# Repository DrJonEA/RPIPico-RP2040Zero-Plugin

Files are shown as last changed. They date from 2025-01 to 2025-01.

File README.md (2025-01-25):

# RPIPico-RP2040Zero-Plugin
Use a RPI Pico in a RP2040Zero Socket for development purposes.

I love the small footprint of the RP2040Zero for some projects. Working with it in development though is a pain as the SWD ports are not exposed. To get around this I build an adapter board so I could use a Raspberry Pi Pico as a plugin for the RP2040 Zero during development.

Included in this repo is the kikad  files and an example project.

The adapter also has a reset switch on it and three LED. One is permanently on. The other two are connected to GP20 and GP21 via jumpers. So you can choose to conect these or not into the circuit.

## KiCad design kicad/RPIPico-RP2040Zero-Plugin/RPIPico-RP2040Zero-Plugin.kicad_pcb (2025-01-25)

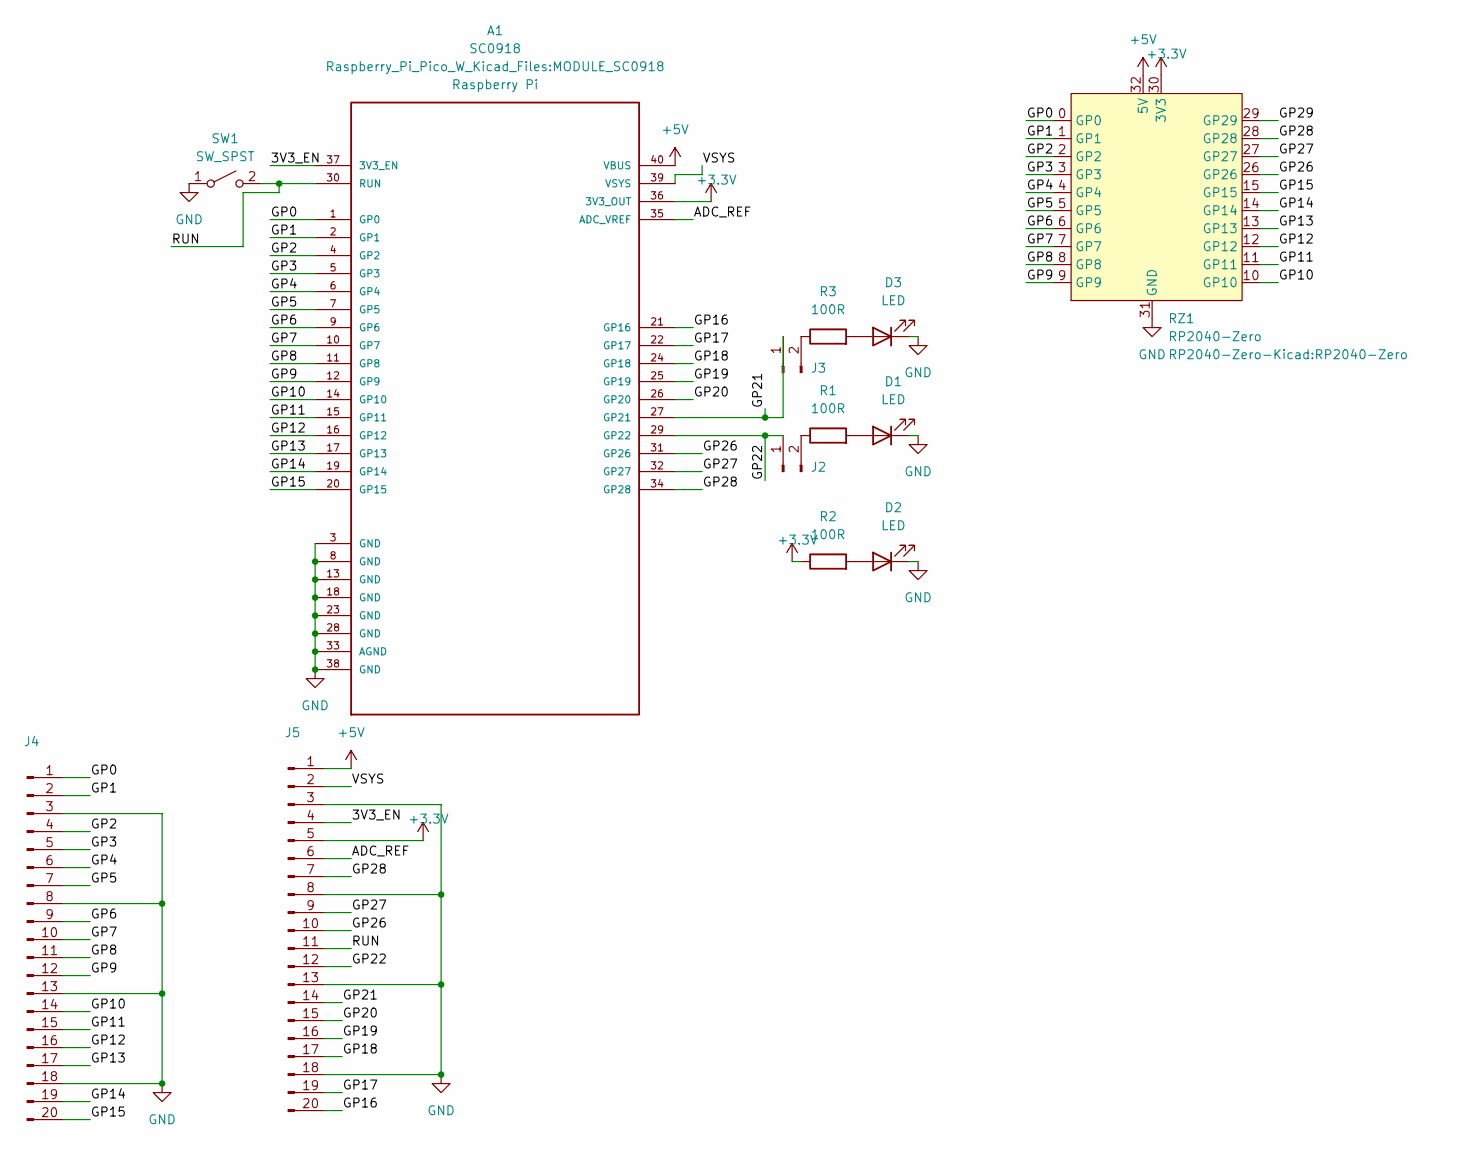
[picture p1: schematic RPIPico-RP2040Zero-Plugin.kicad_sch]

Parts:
A1: SC0918; MODULE_SC0918; PARTREV 1.6
D1, D2, D3: LED; LED_D5.0mm
J2, J3: Conn_01x02_Pin; PinHeader_1x02_P2.54mm_Vertical
J4, J5: Conn_01x20_Pin; PinHeader_1x20_P2.54mm_Vertical
R1, R2, R3: 100R; R_Axial_DIN0309_L9.0mm_D3.2mm_P12.70mm_Horizontal
RZ1: RP2040-Zero
SW1: SW_SPST; SW_PUSH_6mm_H8.5mm

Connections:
+3.3V: A1.36 (3V3_OUT), J5.5, R2.1, RZ1.30 (3V3)
+5V: A1.40 (VBUS), J5.1, RZ1.32 (5V)
/3V3_EN: A1.37 (3V3_EN), J5.4
/ADC_REF: A1.35 (ADC_VREF), J5.6
/GP0: A1.1 (GP0), J4.1, RZ1.0 (GP0)
/GP1: A1.2 (GP1), J4.2, RZ1.1 (GP1)
/GP2: A1.4 (GP2), J4.4, RZ1.2 (GP2)
/GP3: A1.5 (GP3), J4.5, RZ1.3 (GP3)
/GP4: A1.6 (GP4), J4.6, RZ1.4 (GP4)
/GP5: A1.7 (GP5), J4.7, RZ1.5 (GP5)
/GP6: A1.9 (GP6), J4.9, RZ1.6 (GP6)
/GP7: A1.10 (GP7), J4.10, RZ1.7 (GP7)
/GP8: A1.11 (GP8), J4.11, RZ1.8 (GP8)
/GP9: A1.12 (GP9), J4.12, RZ1.9 (GP9)
/GP10: A1.14 (GP10), J4.14, RZ1.10 (GP10)
/GP11: A1.15 (GP11), J4.15, RZ1.11 (GP11)
/GP12: A1.16 (GP12), J4.16, RZ1.12 (GP12)
/GP13: A1.17 (GP13), J4.17, RZ1.13 (GP13)
/GP14: A1.19 (GP14), J4.19, RZ1.14 (GP14)
/GP15: A1.20 (GP15), J4.20, RZ1.15 (GP15)
/GP16: A1.21 (GP16), J5.20
/GP17: A1.22 (GP17), J5.19
/GP18: A1.24 (GP18), J5.17
/GP19: A1.25 (GP19), J5.16
/GP20: A1.26 (GP20), J5.15
/GP21: A1.27 (GP21), J3.1, J5.14
/GP22: A1.29 (GP22), J2.1, J5.12
/GP26: A1.31 (GP26), J5.10, RZ1.26 (GP26)
/GP27: A1.32 (GP27), J5.9, RZ1.27 (GP27)
/GP28: A1.34 (GP28), J5.7, RZ1.28 (GP28)
/GP29: RZ1.29 (GP29)
/RUN: A1.30 (RUN), J5.11, SW1.2 (B)
/VSYS: A1.39 (VSYS), J5.2
GND: A1.3 (GND), A1.8 (GND), A1.13 (GND), A1.18 (GND), A1.23 (GND), A1.28 (GND), A1.33 (AGND), A1.38 (GND), D1.1 (K), D2.1 (K), D3.1 (K), J4.3, J4.8, J4.13, J4.18, J5.3, J5.8, J5.13, J5.18, RZ1.31 (GND), SW1.1 (A)
unnamed: D1.2 (A), R1.2
unnamed: D2.2 (A), R2.2
unnamed: D3.2 (A), R3.2
unnamed: J2.2, R1.1
unnamed: J3.2, R3.1

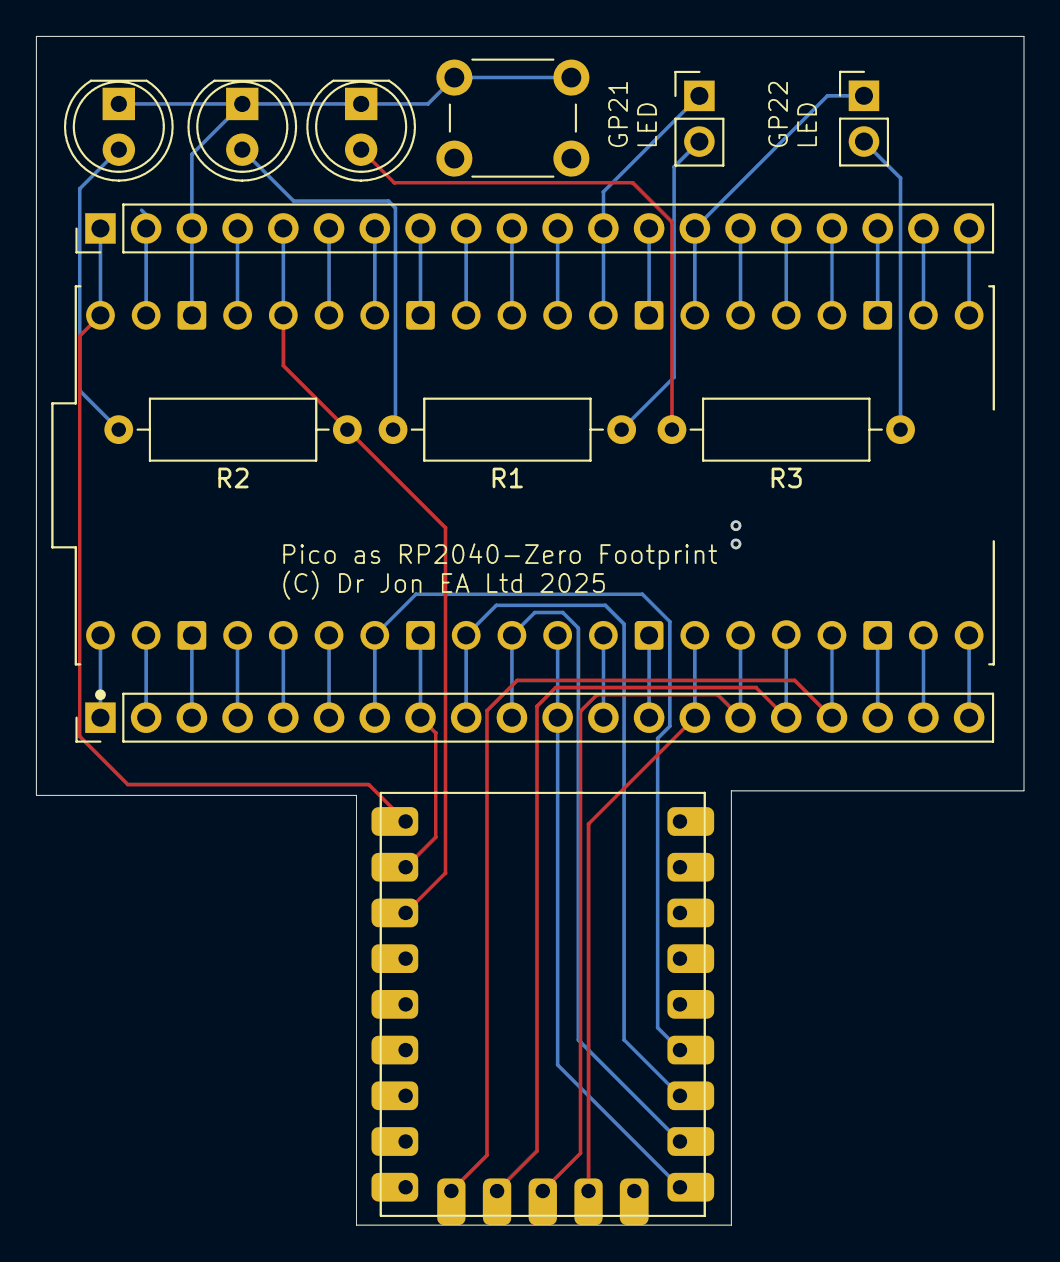
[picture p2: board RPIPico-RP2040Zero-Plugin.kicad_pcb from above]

Board: 4 copper layers, 54.9 x 66.0 mm, 13 parts (0 on the bottom side), 38 nets.

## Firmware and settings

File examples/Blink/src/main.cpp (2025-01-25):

/**
 * Jon Durrant.
 *
 * Blink LEDs on my RPI2040Zero Plugin board
 *
 */

#include "pico/stdlib.h"

#include "RP2040-Plugin.h"
#include <cstdio>


#define DELAY 500 // in microseconds
#define NUM_LEDS 3

int main() {
    uint leds[3] = {PICO_DEFAULT_LED_PIN, LED1, LED2};

    stdio_init_all();
    sleep_ms(2000);

    printf("GO\n");

    for (int i=0; i < NUM_LEDS; i++){
		gpio_init(leds[i]);
		gpio_set_dir(leds[i], GPIO_OUT);
		gpio_put(leds[i], 0);
    }

    for (;;){
    	for (int i=0; i < NUM_LEDS; i++){
    		printf("LED %d\n", i);
			gpio_put(leds[i], 1);
			sleep_ms(DELAY);
			gpio_put(leds[i], 0);
    	}
    }

}
